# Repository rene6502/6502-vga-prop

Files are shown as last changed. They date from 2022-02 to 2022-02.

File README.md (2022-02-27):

# 6502-vga-prop

This project realizes a VGA card, which can be connected to the expansion port of the [6502-cent1](https://github.com/rene6502/6502-cent1).

Features:
-	VGA Signal 640 x 480 @ 60 Hz Industry standard timing
-	Display resolution 320x240 pixels, 40x30 characters, 16 out of 64 colors
-	Single graphics mode using tiles and user-definable character set
-	Integrated funscii system font (2 colors)
-	256 user-defined characters (8x8 pixels, 16 colors) in addition to the system font
-	Memory interface to 6502 bus via 16K dual-port static video RAM (VRAM)
-	Support for double buffering
-	VGA driver extensible by Propeller assembly language

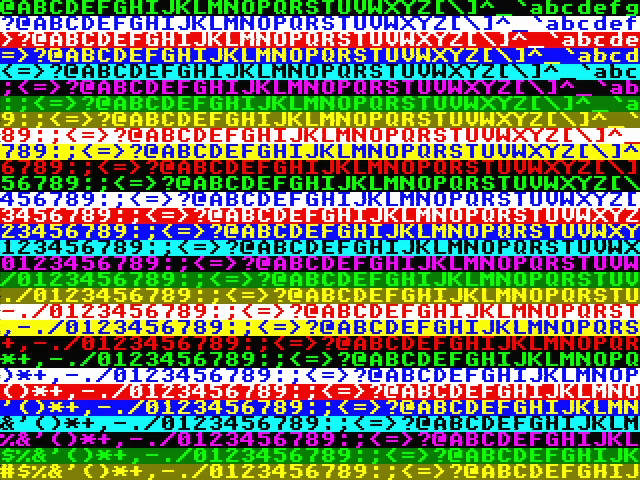
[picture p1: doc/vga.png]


## Hardware

The video signal is generated by a Parallax Propeller 1 using 8 GPIO pins to create a 2-bit RGB, a vertical and a horizontal synch signal.  
The Propeller stores the program in an eeprom and can be programmed via the serial interface.  
Because the Propeller operates at 3.3V a regulator and level shifters are integrated.  
To overcome the limitation of Propeller GPIO pins a binary counter is used to generate the address to the VRAM.  
The 6502 interfaces directly with the VRAM. The 6502 will interact with the VGA via memory, like the old video chips of the 8-bit home-computers.  

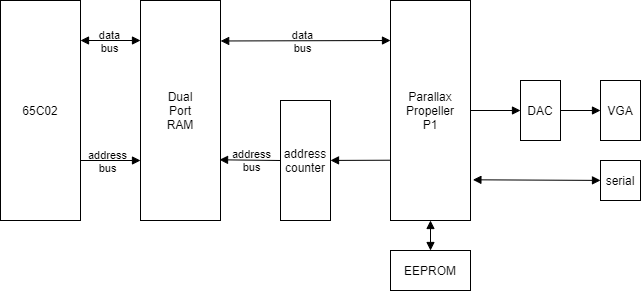
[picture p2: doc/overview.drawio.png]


## Examples

### Hello,World!
Source: [hello-world.asm](demo/hello-world.asm)  
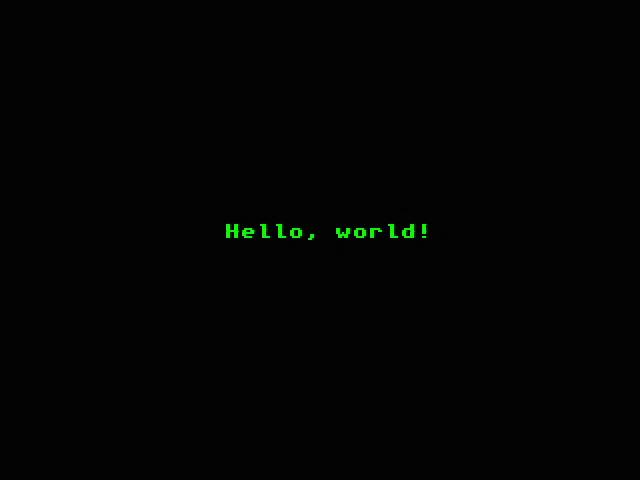
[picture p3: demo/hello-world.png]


### Demo 
Display colorized texts and demonstrates usage of the user-defined character set.  
Source: [vga_demo.asm](demo/vga_demo.asm)  
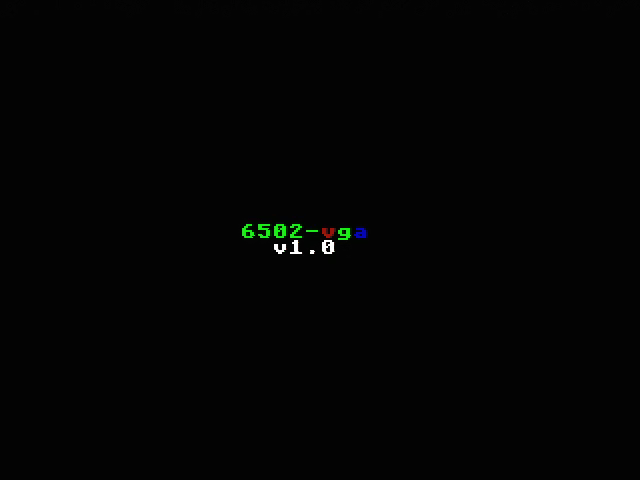
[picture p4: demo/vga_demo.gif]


## Software
The software consists of the vga driver, which is written in Propeller assembly language.  
It makes use of the 320x240 [scanline driver](https://github.com/konimaru/waitvid.2048) from Marko Lukat which uses a single cog.  
6 renderer cogs are used to convert the tilemap into scanlines using the addressed character set.  
A separate vram driver cog is used to read the VRAM memory and copy it to the hub memory, where it can be accessed from the renderer cogs.  
The vram driver copies from VRAM to a separate copy buffer.  
The 6502 can control when and what part of this copy buffer will be transferred to the main hub memory, where it will be read from the renderer cogs (double buffering).  
This copy is done during the vertical blank so that the rendering will not be disturbed by changing the VRAM memory from the 6502.  
The 6502 can control when and what parts should be copied.

**Memory Map**
| area | start | end  | description |
| --- | ----- | ---- | --- |
| ctrl_cmd | 0200  | 0200 | command |
| tilemap  | 0210  | 0B6F | screen tiles |
| palettes | 0B70  | 0C6F | color palettes |
| frame | 0C70  | 0C71 | frame number |
| charset  | 0C80  | 2C7F | user character set |

**ctrl_cmd**  
This register controls which memory will be transferred during the next vertical blank  
bit 0: copy control section  
bit 1: copy tilemap and palettes  
bit 2: copy user-defined character set

**tilemap**  
screen tiles with 40 columns and 30 rows, starting with first row  
each tile is 16 bit, LSB contains the character code and MSB the palette index  
if the bit 4 of the MSB is set to 1 then the user-defined character set is used, otherwise the system character set  

**palettes**  
Table of 16 palettes, each containing 16 colors  
Color is encoded as bit 6-7: R, bit 4-5: G, bit 2-3 B, bit 0-1 always 0  
The system characters use 2 colors, the user-defined characters use 16 colors  

**frame**  
16 bit frame counter, this value is incremented after the buffer was copied during the vertical blank

## Implementation details

### Tilemap and memory map
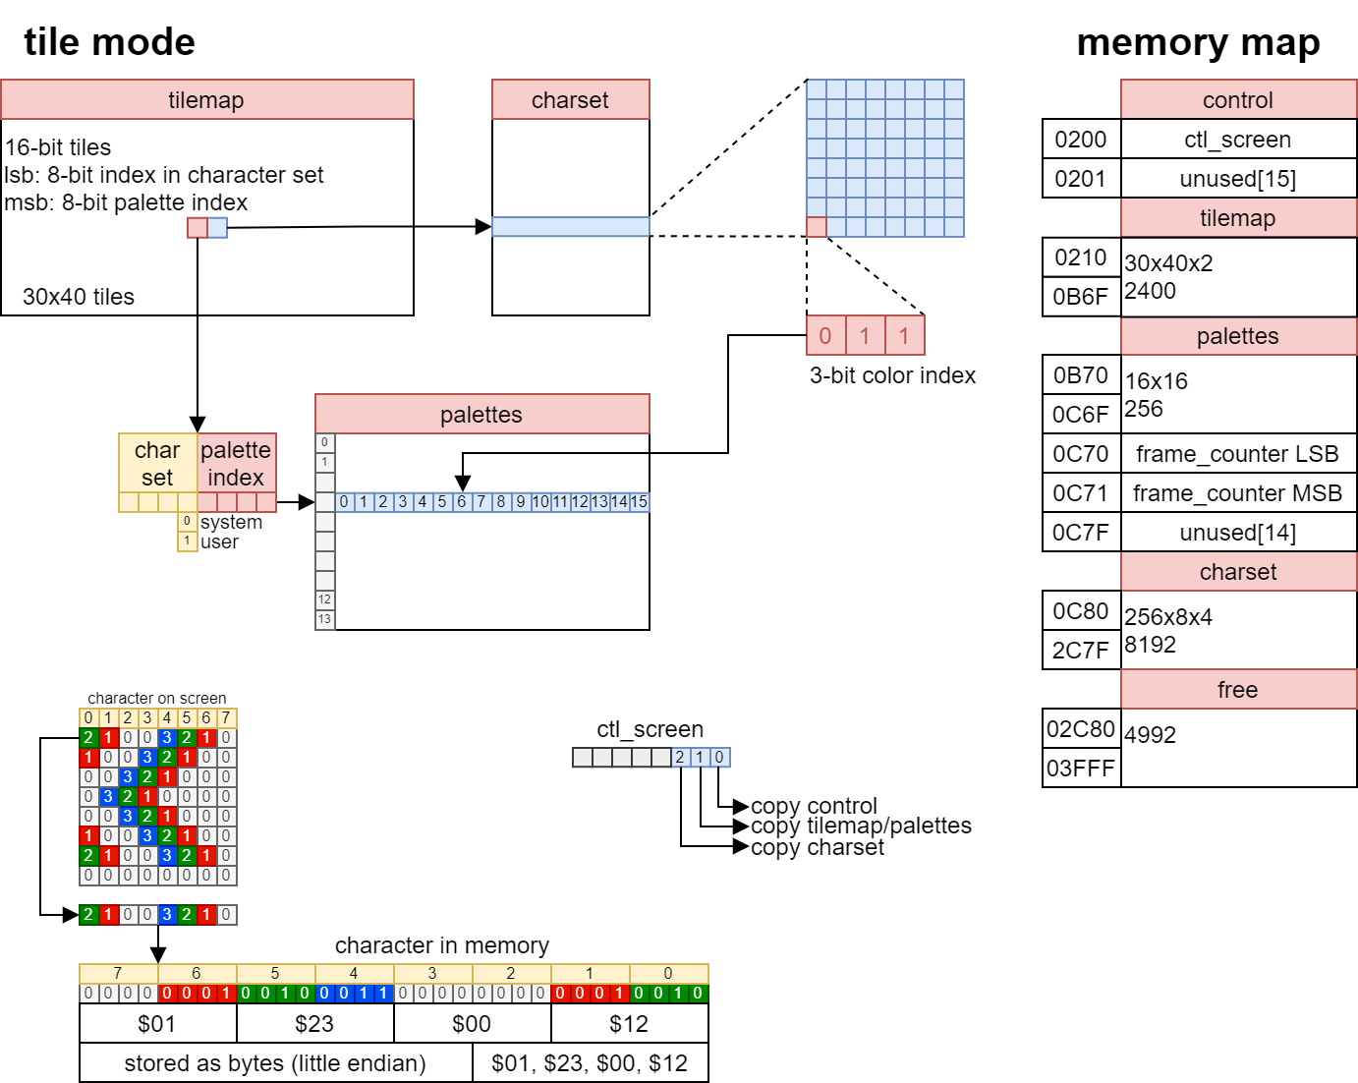
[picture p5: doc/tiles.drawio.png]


### Timing
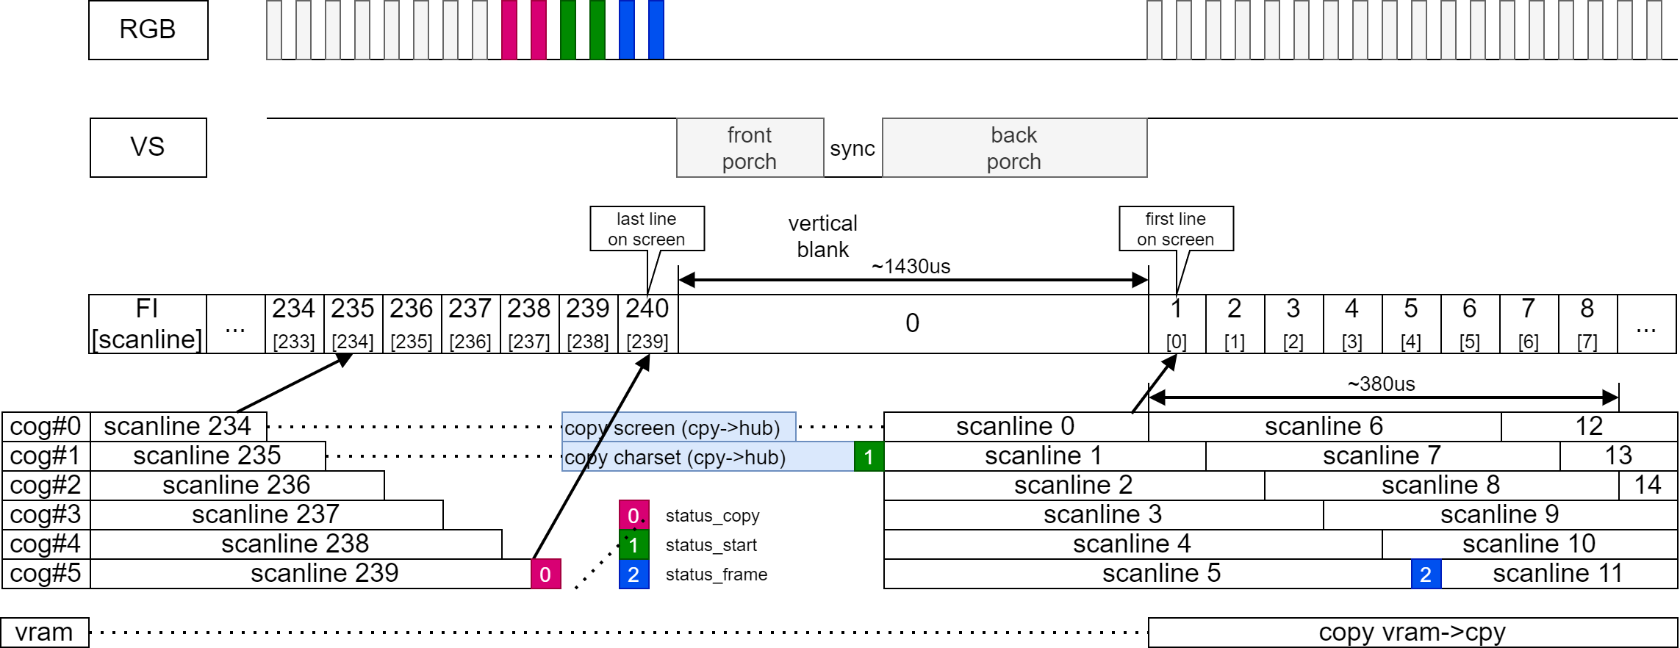
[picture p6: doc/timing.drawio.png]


## Schematics and PCB
- [PDF](doc/schematics.pdf) of schematics
- See the KiCad project in folder [kicad](./kicad)  
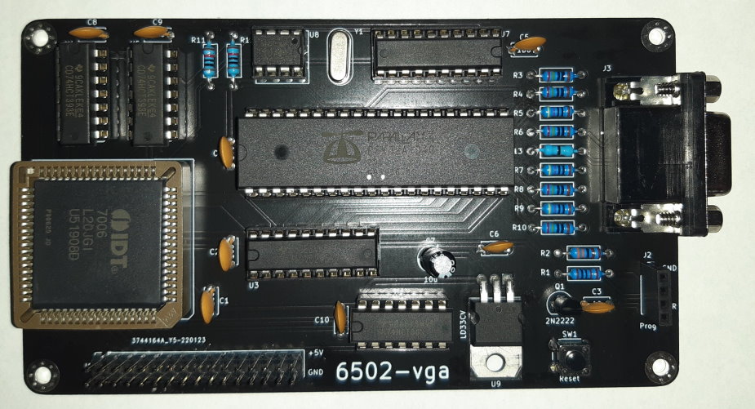
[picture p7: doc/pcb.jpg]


## Connecting vga board with 6502-cent1
The vga board is connected using a 32-pin ribbon IDC cable. The RAM from the mainboard must be removed.  
It is replaced by the 16k VRAM of the vga board using the address space $0000-$3FFF.  
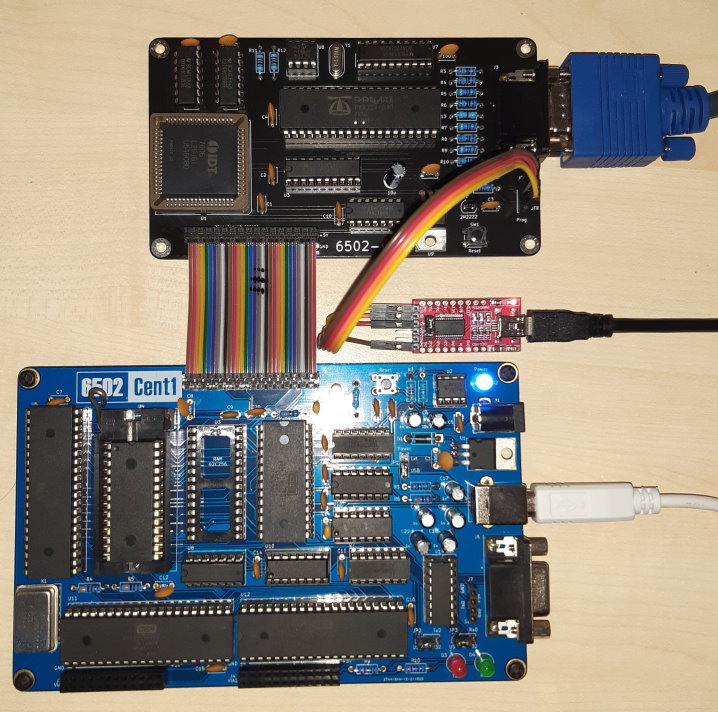
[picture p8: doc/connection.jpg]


## Connect serial to program Parallax Propeller
Initially the Propeller must be programmed with the VGA driver.
To do so a USB-Serial Adapter is required.  
It must provide a DTR signal, which is needed to start the Propeller boot-loading process.  
A working example is [FT232-AZ USB to TTL Serial Adapter for 3.3V and 5V](https://www.az-delivery.de/en/products/ftdi-adapter-ft232rl).  
The spin/assembly program can be compiled and loaded to the eeprom using the [SimpleIDE Software from Parallax](https://www.parallax.com/download/Propeller-1-software).  


Once loaded the vga will show a simple startup screen and is ready to display the tile map.

## Credits
-	Wuerfel21 for the [Funscii font](https://github.com/Wuerfel21/funscii)
-	Marko Lukat for the [scanline video driver](https://github.com/konimaru/waitvid.2048)
- Adam Saltsman for the ["1985" tileset](https://adamatomic.itch.io/1985)

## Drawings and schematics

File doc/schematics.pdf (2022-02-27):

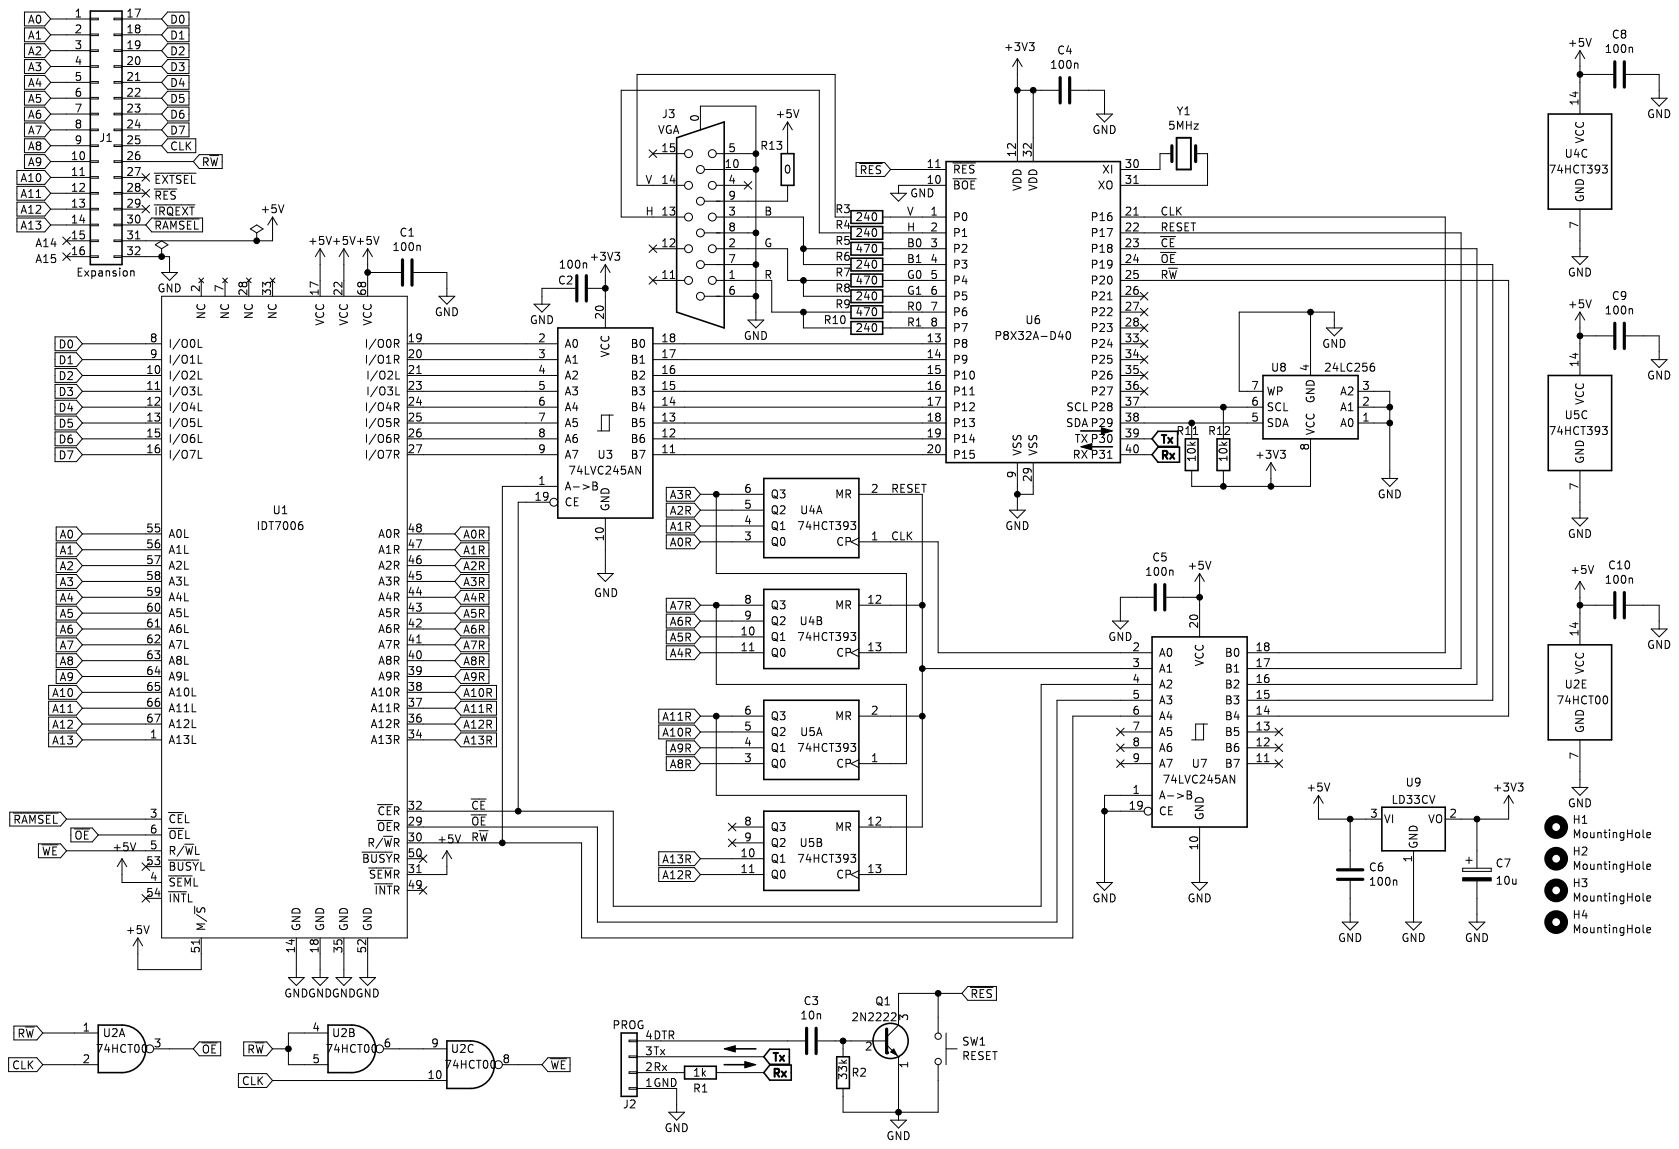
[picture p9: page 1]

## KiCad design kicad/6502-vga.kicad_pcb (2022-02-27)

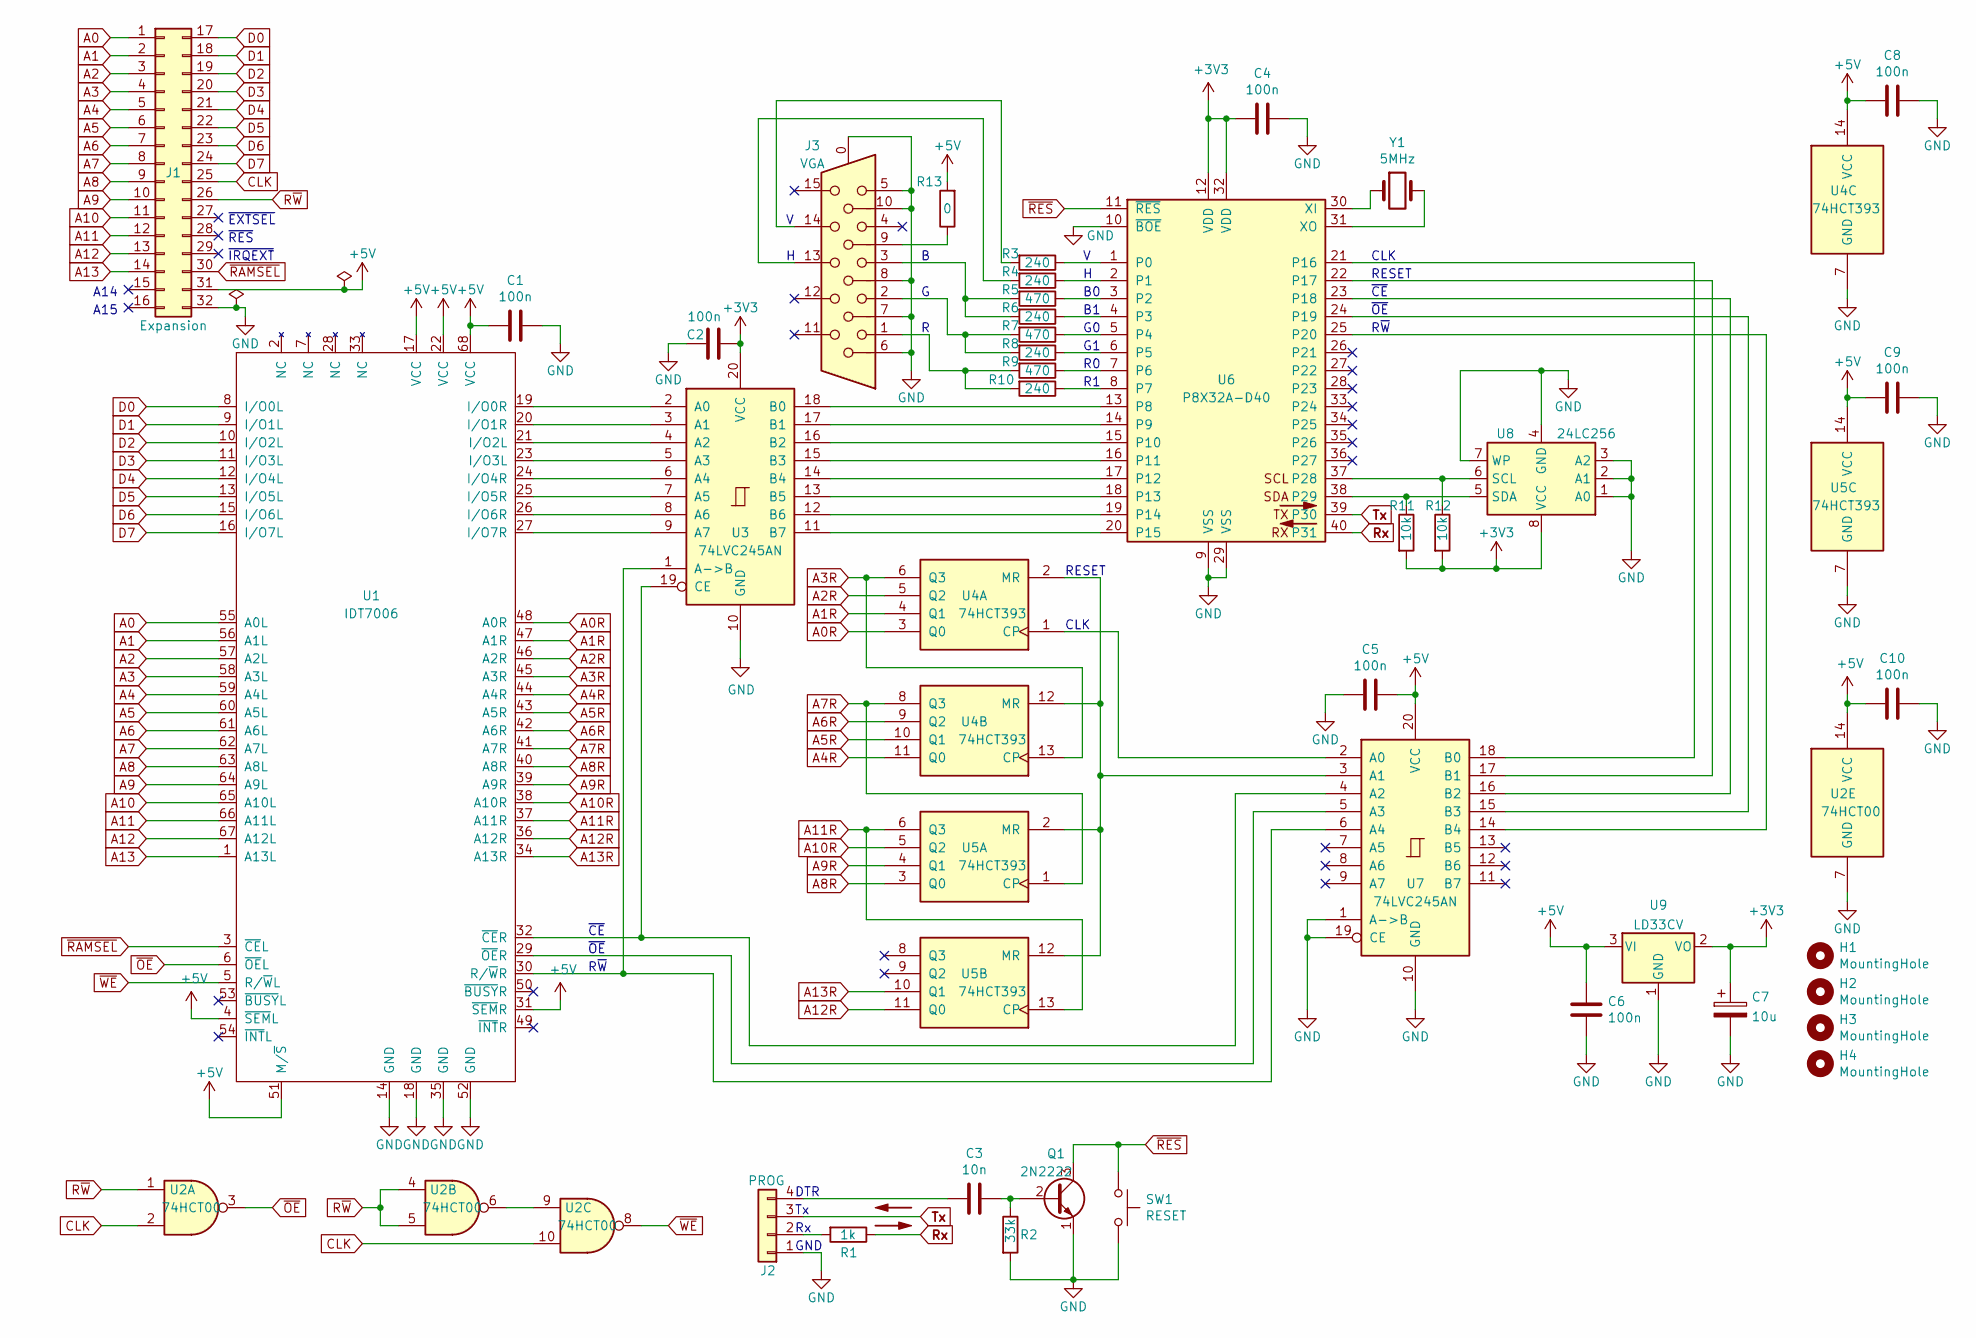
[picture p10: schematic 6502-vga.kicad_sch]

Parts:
C1, C2, C4, C5, C6, C8, C9, C10: 100n; C_Disc_D5.0mm_W2.5mm_P5.00mm
C3: 10n; C_Disc_D5.0mm_W2.5mm_P5.00mm
C7: 10u; CP_Radial_D5.0mm_P2.00mm
H1, H2, H3, H4: MountingHole; MountingHole_3.2mm_M3_Pad_Via
J1: Expansion; PinSocket_2x16_P2.54mm_Vertical
J2: PROG; PinSocket_1x04_P2.54mm_Vertical
J3: VGA; DSUB-15-HD_Female_Horizontal_P2.29x1.98mm_EdgePinOffset8.35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
Q1: 2N2222; TO-92
R1: 1k; R_Axial_DIN0207_L6.3mm_D2.5mm_P10.16mm_Horizontal
R2: 33k; R_Axial_DIN0207_L6.3mm_D2.5mm_P10.16mm_Horizontal
R3, R4, R6, R8, R10: 240; R_Axial_DIN0207_L6.3mm_D2.5mm_P10.16mm_Horizontal
R5, R7, R9: 470; R_Axial_DIN0207_L6.3mm_D2.5mm_P10.16mm_Horizontal
R11, R12: 10k; R_Axial_DIN0207_L6.3mm_D2.5mm_P10.16mm_Horizontal
R13: 0; R_Axial_DIN0207_L6.3mm_D2.5mm_P10.16mm_Horizontal
SW1: RESET; SW_PUSH_6mm_H4.3mm
U1: IDT7006; PLCC-68_THT-Socket
U2: 74HCT00; DIP-14_W7.62mm_LongPads
U3, U7: 74LVC245AN; DIP-20_W7.62mm_LongPads
U4, U5: 74HCT393; DIP-14_W7.62mm_LongPads
U6: P8X32A-D40; DIP-40_W15.24mm_LongPads
U8: 24LC256; DIP-8_W7.62mm_Socket_LongPads
U9: LD33CV; TO-220-3_Horizontal_TabDown
Y1: 5MHz; Crystal_HC49-U_Vertical

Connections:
+3V3: C2.1, C4.2, C7.1, R11.2, R12.2, U3.20 (VCC), U6.12 (VDD), U6.32 (VDD), U8.8 (VCC), U9.2 (VO)
+5V: C1.2, C5.1, C6.1, C8.2, C9.2, C10.2, J1.31, R13.2, U1.4 (~SEML), U1.17 (VCC), U1.22 (VCC), U1.31 (~SEMR), U1.51 (M/~S), U1.68 (VCC), U2.14 (VCC), U4.14 (VCC), U5.14 (VCC), U7.20 (VCC), U9.3 (VI)
A0: J1.1, U1.55 (A0L)
A0R: U1.48 (A0R), U4.3 (Q0)
A1: J1.2, U1.56 (A1L)
A1R: U1.47 (A1R), U4.4 (Q1)
A2: J1.3, U1.57 (A2L)
A2R: U1.46 (A2R), U4.5 (Q2)
A3: J1.4, U1.58 (A3L)
A3R: U1.45 (A3R), U4.6 (Q3), U4.13 (CP)
A4: J1.5, U1.59 (A4L)
A4R: U1.44 (A4R), U4.11 (Q0)
A5: J1.6, U1.60 (A5L)
A5R: U1.43 (A5R), U4.10 (Q1)
A6: J1.7, U1.61 (A6L)
A6R: U1.42 (A6R), U4.9 (Q2)
A7: J1.8, U1.62 (A7L)
A7R: U1.41 (A7R), U4.8 (Q3), U5.1 (CP)
A8: J1.9, U1.63 (A8L)
A8R: U1.40 (A8R), U5.3 (Q0)
A9: J1.10, U1.64 (A9L)
A9R: U1.39 (A9R), U5.4 (Q1)
A10: J1.11, U1.65 (A10L)
A10R: U1.38 (A10R), U5.5 (Q2)
A11: J1.12, U1.66 (A11L)
A11R: U1.37 (A11R), U5.6 (Q3), U5.13 (CP)
A12: J1.13, U1.67 (A12L)
A12R: U1.36 (A12R), U5.11 (Q0)
A13: J1.14, U1.1 (A13L)
A13R: U1.34 (A13R), U5.10 (Q1)
CLK: J1.25, U2.2, U2.10
D0: J1.17, U1.8 (I/O0L)
D1: J1.18, U1.9 (I/O1L)
D2: J1.19, U1.10 (I/O2L)
D3: J1.20, U1.11 (I/O3L)
D4: J1.21, U1.12 (I/O4L)
D5: J1.22, U1.13 (I/O5L)
D6: J1.23, U1.15 (I/O6L)
D7: J1.24, U1.16 (I/O7L)
GND: C1.1, C2.2, C4.1, C5.2, C6.2, C7.2, C8.1, C9.1, C10.1, J1.32, J2.1, J3.0, J3.5, J3.6, J3.7, J3.8, J3.10, Q1.1 (E), R2.2, SW1.2, U1.14 (GND), U1.18 (GND), U1.35 (GND), U1.52 (GND), U2.7 (GND), U3.10 (GND), U4.7 (GND), U5.7 (GND), U6.9 (VSS), U6.10 (~BOE), U6.29 (VSS), U7.1 (A->B), U7.10 (GND), U7.19 (CE), U8.1 (A0), U8.2 (A1), U8.3 (A2), U8.4 (GND), U8.7 (WP), U9.1 (GND)
unnamed: C3.1, Q1.2 (B), R2.1
unnamed: C3.2, J2.4
unnamed: J2.2, R1.2
unnamed: J3.1, R9.2, R10.2
unnamed: J3.2, R7.2, R8.2
unnamed: J3.3, R5.2, R6.2
unnamed: J3.9, R13.1
unnamed: J3.13, R4.2
unnamed: J3.14, R3.2
unnamed: R3.1, U6.1 (P0)
unnamed: R4.1, U6.2 (P1)
unnamed: R5.1, U6.3 (P2)
unnamed: R6.1, U6.4 (P3)
unnamed: R7.1, U6.5 (P4)
unnamed: R8.1, U6.6 (P5)
unnamed: R9.1, U6.7 (P6)
unnamed: R10.1, U6.8 (P7)
unnamed: R11.1, U6.38 (P29), U8.5 (SDA)
unnamed: R12.1, U6.37 (P28), U8.6 (SCL)
unnamed: U1.19 (I/O0R), U3.2 (A0)
unnamed: U1.20 (I/O1R), U3.3 (A1)
unnamed: U1.21 (I/O2L), U3.4 (A2)
unnamed: U1.23 (I/O3L), U3.5 (A3)
unnamed: U1.24 (I/O4R), U3.6 (A4)
unnamed: U1.25 (I/O5R), U3.7 (A5)
unnamed: U1.26 (I/O6R), U3.8 (A6)
unnamed: U1.27 (I/O7R), U3.9 (A7)
unnamed: U1.29 (~OER), U7.5 (A3)
unnamed: U1.30 (R/~WR), U3.1 (A->B), U7.6 (A4)
unnamed: U1.32 (~CER), U3.19 (CE), U7.4 (A2)
unnamed: U2.6, U2.9
unnamed: U3.11 (B7), U6.20 (P15)
unnamed: U3.12 (B6), U6.19 (P14)
unnamed: U3.13 (B5), U6.18 (P13)
unnamed: U3.14 (B4), U6.17 (P12)
unnamed: U3.15 (B3), U6.16 (P11)
unnamed: U3.16 (B2), U6.15 (P10)
unnamed: U3.17 (B1), U6.14 (P9)
unnamed: U3.18 (B0), U6.13 (P8)
unnamed: U4.1 (CP), U7.2 (A0)
unnamed: U4.2 (MR), U4.12 (MR), U5.2 (MR), U5.12 (MR), U7.3 (A1)
unnamed: U6.21 (P16), U7.18 (B0)
unnamed: U6.22 (P17), U7.17 (B1)
unnamed: U6.23 (P18), U7.16 (B2)
unnamed: U6.24 (P19), U7.15 (B3)
unnamed: U6.25 (P20), U7.14 (B4)
unnamed: U6.30 (XI), Y1.1
unnamed: U6.31 (XO), Y1.2
Rx: R1.1, U6.40 (P31)
R~W: J1.26, U2.1, U2.4, U2.5
Tx: J2.3, U6.39 (P30)
~OE: U1.6 (~OEL), U2.3
~RAMSEL: J1.30, U1.3 (~CEL)
~RES: Q1.3 (C), SW1.1, U6.11 (~RES)
~WE: U1.5 (R/~WL), U2.8

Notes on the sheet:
~{EXTSEL}
R~{W}
RESET
GND
~{RES}
A15
~{CE}
~{OE}
~{IRQEXT}
CLK
A14
DTR

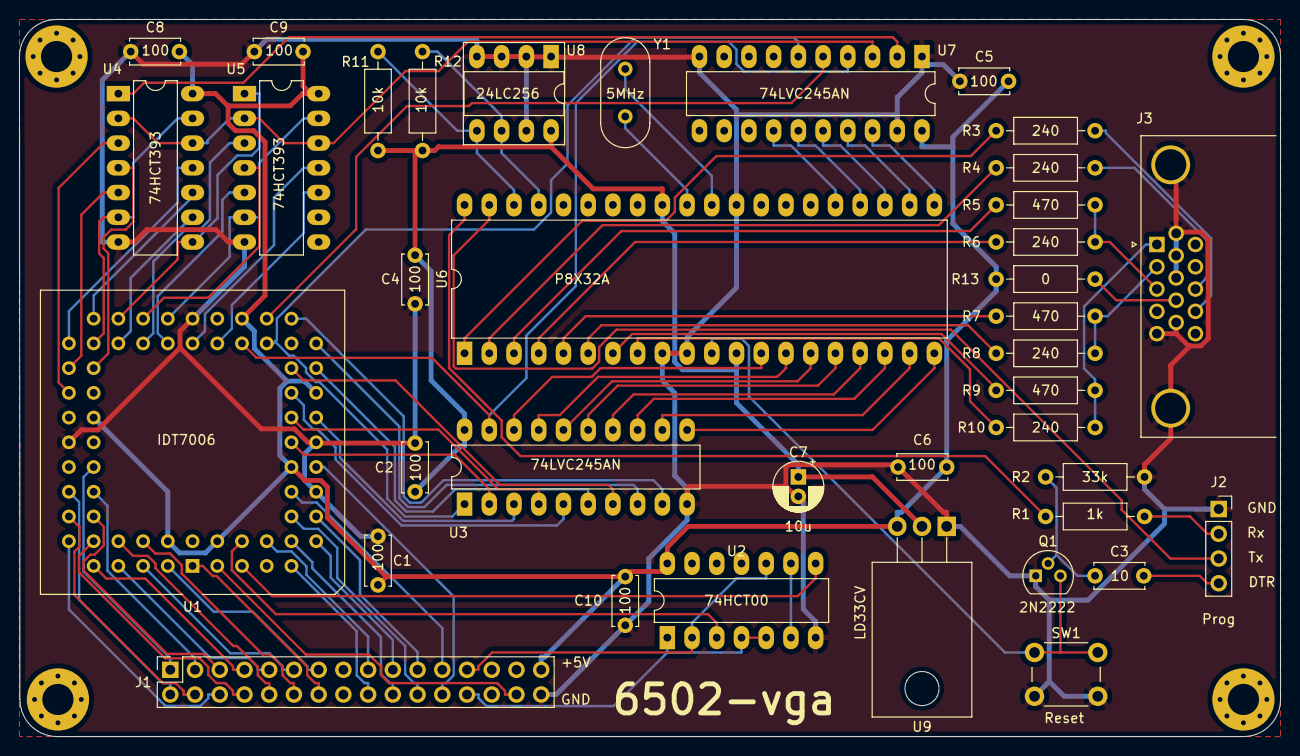
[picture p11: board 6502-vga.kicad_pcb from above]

Board: 2 copper layers, 129.5 x 73.7 mm, 42 parts (0 on the bottom side), 95 nets.

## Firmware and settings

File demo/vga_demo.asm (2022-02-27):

* = $2d00

CLOCK_MHZ   = 1 ; // clock frequency in MHz

VIDEO_START = $0200
VIDEO_END   = $2c7f
CTL_SCREEN  = $0200
TILEMAP     = $0210
PALETTES    = $0b70
FRAME       = $0c70
CHARSET     = $0c80
SIM         = $fff8 ; 1 -> simulation running
SCREEN_NONE = %0000
SCREEN_CTRL = %0001
SCREEN_TILE = %0010
SCREEN_CHAR = %0100
DELAY       = 2

BLACK       = $00
WHITE       = $fc
DARK_GREEN  = $10
GREEN       = $30
BLUE        = $0c
RED         = $c0
DARK_YELLOW = $50
YELLOW      = $f0
CYAN        = $3c
MAGENTA     = $cc


; zero page
            .virtual $00
TEMP        .byte ? ; general purpose byte, always assume that subroutines will change this
TEMP_X      .byte ? ; X register backup
TEMP_Y      .byte ? ; Y register backup
POS_X       .byte ? ; x screen position
POS_Y       .byte ? ; y screen position
CUR_X       .byte ? ; current x screen position
CUR_Y       .byte ? ; current y screen position
CHAR        .byte ? ; character
PALETTE     .byte ? ; palette index
TILE_ADDRL  .byte ? ; tile address
TILE_ADDRH  .byte ? ; tile address
SRC_ADDRL   .byte ? ; copy source start address
SRC_ADDRH   .byte ? ; copy source start address
END_ADDRL   .byte ? ; copy source end address
END_ADDRH   .byte ? ; copy source end address
DEST_ADDRL  .byte ? ; copy destination address
DEST_ADDRH  .byte ? ; copy destination address
WAIT_COUNT  .byte ? ; number of 200ms delays

            .endvirtual

start:
        jsr clear_memory
        jsr clear_screen
        jsr init_palette
        
        jsr demo_charset1
        jsr wait
        
        jsr demo_charset2
        jsr wait
        
        jsr demo_colors
        jsr wait
        
        jsr demo_tiles
        jsr wait
        
        rts

        
demo_charset1:
        jsr clear_screen
        lda #1 ; blue on white
        sta PALETTE
        lda #12
        sta POS_X
        lda #7
        sta POS_Y
        jsr draw_charset
        lda #SCREEN_CTRL | SCREEN_TILE
        jsr copy_vram
        rts

demo_charset2:
        lda #0
        sta POS_Y
        lda #0
        sta PALETTE
_next_row:        
        lda #12
        lda #'A'
        clc
        sbc POS_Y
        sta CHAR
        jsr fill_row
        inc POS_Y
        inc PALETTE
        lda PALETTE
        cmp #11
        bne _next_palette
        lda #0
        sta PALETTE
_next_palette:        
        lda POS_Y
        cmp #30
        bne _next_row
        lda #SCREEN_CTRL | SCREEN_TILE
        jsr copy_vram
        rts

; IN  POS_Y        row to render 0..29
; IN  CHAR         first character (incremented after each row)
fill_row:
        jsr calc_tileaddr
        ldy #0
_next_char:        
        lda CHAR
        sta (TILE_ADDRL), y
        inc CHAR
        iny
        lda PALETTE
        sta (TILE_ADDRL), y
        iny
        cpy #40*2
        bne _next_char
        rts             

demo_colors:
        jsr create_colorset
        jsr clear_screen
        lda #12
        sta POS_X
        lda #7
        sta POS_Y
        jsr draw_colors
        lda #SCREEN_CTRL | SCREEN_TILE
        jsr copy_vram
        rts

demo_tiles:
        jsr init_charset
        jsr fill_map
        lda #SCREEN_CTRL | SCREEN_TILE |  SCREEN_CHAR
        jsr copy_vram
        rts

; fill screen with map
fill_map:
        lda #<map
        sta SRC_ADDRL
        lda #>map
        sta SRC_ADDRH
        lda #0
        sta POS_Y
_next_row:        
        jsr calc_srcaddr
        jsr calc_tileaddr
        lda #0
        sta POS_X
_next_col:
        lda POS_X
        asl
        sta TEMP_Y
        lda POS_X
        tay
        lda (SRC_ADDRL), y
        ldy TEMP_Y
        sta (TILE_ADDRL), y
        lda #$1b ; user-defined charset, palette 11
        iny
        sta (TILE_ADDRL), y
        inc POS_X
        lda POS_X
        cmp #40
        bne _next_col
        inc POS_Y
        lda POS_Y
        cmp #29
        bne _next_row
        rts

; calculate address of first tile in row
; IN: POS_Y
; OUT: TILE_ADDRL/H
; MD: A
calc_srcaddr:
        lda POS_Y
        asl A
        tax
        clc
        lda #<map
        adc mul40,x 
        sta SRC_ADDRL ; LSB address of first tile in row
        inx
        lda #>map
        adc mul40,x 
        sta SRC_ADDRH ; LSB address of first tile in row
        rts               

init_charset:
        lda #<tile_charset
        sta SRC_ADDRL
        lda #>tile_charset
        sta SRC_ADDRH
        lda #<tile_charset_end
        sta END_ADDRL
        lda #>tile_charset_end
        sta END_ADDRH
        lda #<CHARSET
        sta DEST_ADDRL
        lda #>CHARSET
        sta DEST_ADDRH
        jsr copy_bytes
        rts                 

create_colorset:
        lda #<CHARSET
        sta DEST_ADDRL
        lda #>CHARSET
        sta DEST_ADDRH
        lda #0
        sta CHAR ; 0..15
_next_char:        
        ldx #32
        ldy #0
        lda CHAR
        asl
        asl
        asl
        asl
        ora CHAR
_next_byte:
        sta (DEST_ADDRL), y
        inc DEST_ADDRL
        bne _skip_inc
        inc DEST_ADDRH
_skip_inc:
        dex
        bne _next_byte
        inc CHAR
        lda CHAR
        cmp #16
        bne _next_char
        lda #SCREEN_CHAR
        jsr copy_vram
        rts        

         
; draws charset at x=POS_X and y=POS_Y using palette index in PALETTE
draw_charset:
        lda #0
        sta CHAR
_next_y:        
        jsr calc_tileaddr
        lda POS_X
        asl A
        tay
        ldx #0
_next_x:        
        lda CHAR
        sta (TILE_ADDRL), y
        iny
        lda PALETTE
        sta (TILE_ADDRL), y
        iny
        inc CHAR
        inx
        cpx #16
        bne _next_x
        inc POS_Y
        lda POS_Y
        cmp #7+16
        bne _next_y
        rts
        

; draws colors at x=POS_X and y=POS_Y
draw_colors:
        lda #0
        sta CUR_X
        sta CUR_Y
_next_y:
        jsr calc_tileaddr
        lda POS_X
        asl
        tay
_next_x:
        lda CUR_X
        lsr
        clc
        adc #0
        sta TEMP
        lda CUR_Y
        lsr
        and #$01
        beq _even
        clc
        lda TEMP
        adc #8
        sta TEMP
_even:  
        lda TEMP      
        sta (TILE_ADDRL), y
        iny
        lda CUR_Y
        lsr
        lsr
        clc
        adc #$1c ; set user-defined charset bit and start palette 12
        sta (TILE_ADDRL), y
        iny
        inc CUR_X
        lda CUR_X
        cmp #16
        bne _next_x
        lda #0
        sta CUR_X
        inc CUR_Y
        inc POS_Y
        lda CUR_Y
        cmp #16
        bne _next_y
        rts
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
